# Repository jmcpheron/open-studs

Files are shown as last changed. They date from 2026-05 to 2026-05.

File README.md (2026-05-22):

# open-studs

**Design your own 3D-printable studded TPU bracelet in the browser.** Pick the
bracelet size, stud style, pattern, latch, and print stage, then export JSON or
OpenSCAD for STL generation.

[**Start Designing**](https://jmcpheron.github.io/open-studs/configurator/) ·
[Design Architecture](https://jmcpheron.github.io/open-studs/design-architecture.html) ·
[Latch Lab](https://jmcpheron.github.io/open-studs/latch-lab.html) ·
[Contributing](CONTRIBUTING.md)

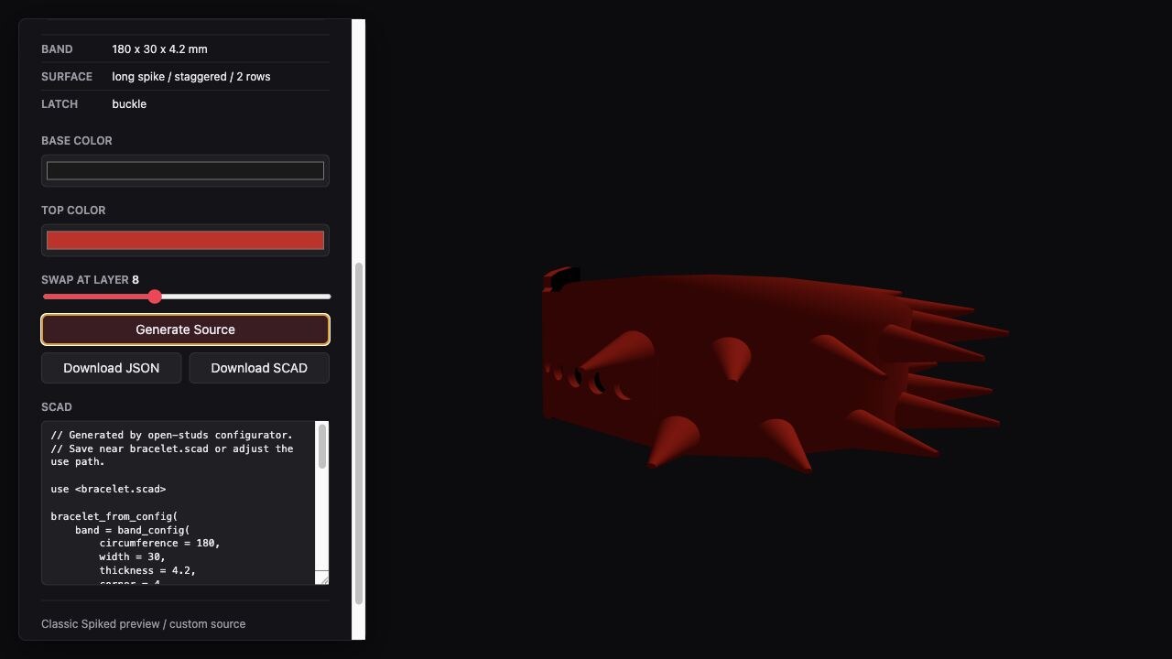
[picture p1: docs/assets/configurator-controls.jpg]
open-studs bracelet configurator


The configurator starts from printable presets, then lets you adjust the core
bracelet geometry: length, width, thickness, stud type, stud layout, attachment
mode, latch, and test-print stage. The preview shows the bracelet worn curved
around a wrist or laid flat in print orientation.

| Design in the Browser | Print-Orientation Preview |
| --- | --- |
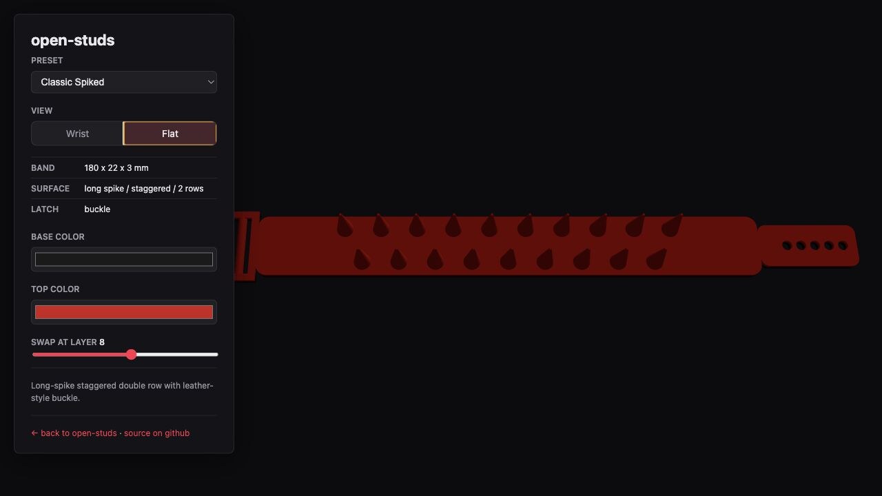
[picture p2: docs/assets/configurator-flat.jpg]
Flat print preview
| Configurator controls |  |

## Start Here

1. Open the [bracelet configurator](https://jmcpheron.github.io/open-studs/configurator/).
2. Choose a preset, then adjust band size, stud style, pattern, latch, and export stage.
3. Download JSON or SCAD. Build locally with `uv run studslab build-config configs/example_bracelet.json -o build/custom.stl`, or use the manual `build-config` GitHub Action.







**Parametric, 3D-printable studded bracelets in TPU.** Punk-and-metal aesthetic,
flexible like leather, open-source like it should be.

Designed in OpenSCAD. Browse presets at [jmcpheron.github.io/open-studs](https://jmcpheron.github.io/open-studs). Clone the repo to add your own stud designs, latches, or take it somewhere new.

This repo follows the **[Shareable CAD](SHAREABLE-CAD.md)** pattern: OpenSCAD as the parametric source-of-truth, Python kernel (`studslab`, `explainers`) for deconstruction, GitHub as the workshop, MakerWorld + Printables as the storefronts.

---

## What this is

A kit, not a single model. The band, the studs, the latches, and the placement patterns are all separate modules — mix and match to build the bracelet you want. Three ways to use it:

- **Just want to print one?** Grab a preset from [Printables](#) or [MakerWorld](#).
- **Want to customize?** Use the [web configurator](https://jmcpheron.github.io/open-studs/configurator/) — export JSON for `uv run studslab build-config` or SCAD for direct OpenSCAD builds.
- **Want to design your own?** Clone the repo, edit the OpenSCAD source, PR a new stud or latch back. Contributor docs in [CONTRIBUTING.md](CONTRIBUTING.md).

## Stud modes

Three ways to build a stud:

1. **Integral studs** — studs printed as part of the band in one piece. Cleanest look, single print, single color (unless you do a color-change pause or have multi-material).
2. **Modular studs** — band and studs printed separately, friction-fit or glued. Unlocks the iconic silver-on-black look without needing a multi-material printer.
3. **Bare band with attachment holes** — band only, with a grid of through-holes. Bring your own studs: foam spikes, metal hardware, rhinestones, fabric pieces, sewn-on whatever. The bracelet becomes a substrate.

## Built-in stud designs

- Classic pyramid
- Flat (low-profile) pyramid
- Dome / half-sphere
- Cone spike
- Long spike (the dramatic one)
- Diamond
- Screw-head (flat round)
- *...and whatever the community adds*

## Latch options

Different tradeoffs — none is universally best:

- **Buckle (pin-through-hole)** — most leather-bracelet-authentic, adjustable for wrist size, very secure
- **Snap button (printed peg + socket)** — lowest profile, fastest to put on
- **Loop-and-post / toggle** — secure, hides well under studs
- **Friction overlap** — no hardware, fully adjustable, TPU-on-TPU grip (may slip in heavy use)
- **Magnetic insert pocket** — premium feel, requires a small neodymium magnet
- *...and whatever the community adds*

Experimental latch coupons live in [docs/latch-lab.md](docs/latch-lab.md):
`mushroom_keyhole`, `ladder_strap`, and `loop_post_v2`.

## Sizing

**Print a test strip before committing to a full bracelet.** TPU stretch varies by brand and infill, and wrist sizes vary more than you'd think. The repo includes `sizing_test.scad` plus focused coupons under `test_prints/` for flex relief, surface attachment, and latch fit.

Rough guide:
- Kid: 140–160mm circumference
- Small adult: 160–180mm
- Medium adult: 175–195mm
- Large adult: 190–215mm

## Printing notes

- **Filament:** TPU 95A is the sweet spot — flexible enough to slip on, stiff enough to hold studs. TPU 85A works but is floppy. TPU 98A+ is too stiff for the friction latch mode.
- **Layer height:** 0.2mm is fine. 0.15mm for cleaner stud detail.
- **Infill:** 100% — TPU prints best as solid perimeters; partial infill on flexible parts looks bad and weakens the band.
- **Supports:** generally no. The studs are designed to print without support; check the preview if you're modifying placement.
- **Speed:** slow down for TPU. 20–30mm/s is typical.
- **Tip radius:** the spike-style studs have a `tip_radius` parameter. Default is rounded for safety. Set to zero for the full sharp aesthetic — your call, your wrist.

## Repository layout

```
open-studs/
├── bracelet.scad           # public assembly entry point
├── core/                   # band, surface, latch, and config assembly layers
├── sizing_test.scad        # calibration strip — print this first
├── studs/                  # one file per stud design
│   ├── pyramid.scad
│   ├── dome.scad
│   ├── cone_spike.scad
│   ├── long_spike.scad
│   ├── diamond.scad
│   ├── flat_pyramid.scad
│   └── screw_head.scad
├── latches/                # one file per latch
│   ├── buckle.scad
│   ├── snap.scad
│   ├── loop_post.scad
│   ├── friction_overlap.scad
│   └── magnetic.scad
├── patterns/               # stud placement strategies
│   ├── single_row.scad
│   ├── double_row.scad
│   ├── staggered.scad
│   ├── cluster.scad
│   └── gradient_size.scad
├── presets/                # ready-to-print hero configurations
│   ├── classic_spiked.scad
│   ├── festival_wide.scad
│   └── subtle_daily.scad
├── test_prints/            # focused fit and attachment coupons
├── docs/                   # configurator (GitHub Pages)
└── gallery/                # printed examples
```

## Quick start (OpenSCAD)

```scad
use <bracelet.scad>

studded_bracelet(
    circumference = 180,
    width         = 22,
    thickness     = 3,
    stud_module   = "long_spike",
    stud_pattern  = "staggered",
    stud_rows     = 2,
    latch         = "buckle",
    mode          = "integral"   // or "modular" or "bare_with_holes"
);
```

## Contributing

The whole point is that you can add your own studs and latches and PR them back. See [CONTRIBUTING.md](CONTRIBUTING.md) — there's a template stud file, a shared module signature every stud must implement, and a checklist for getting your design merged.
The current band/surface/latch/export split is documented in [docs/design-architecture.md](docs/design-architecture.md).

Particularly looking for:
- New stud designs (especially anything that captures a specific subculture — goth, festival, cyberpunk, kawaii, etc.)
- New latch mechanisms with different tradeoffs
- Multi-material / AMS-aware variants
- Form-factor extensions (collars, chokers, belts, guitar straps — the stud library is reusable)

## License

Dual-licensed:

- **Source code** (`.scad` files, configurator JS, build scripts) — [MIT](LICENSE-MIT)
- **Design output and docs** (STL files, 3MF presets, printed objects, photos, gallery, README) — [CC BY 4.0](LICENSE-CC-BY)

Both licenses are permissive. You can use this commercially, modify it, sell prints of it, ship it inside a closed-source product — anything. The only requirement is attribution: credit `open-studs` and link back. For source code, that means keeping the copyright notice and MIT text in the files. For physical prints or marketplace listings, that means a visible credit somewhere reasonable (product description, included card, etc.).

Modifications you make can be released under whatever license you want, including closed/proprietary — but the original `open-studs` work stays under these licenses for everyone, forever.

## Credits

Built by Jason McPheron. Punk aesthetic direction by Audrey. Contributions from [the community](https://github.com/jmcpheron/open-studs/graphs/contributors).

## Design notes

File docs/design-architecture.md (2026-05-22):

# Bracelet Design Architecture

`open-studs` now separates the bracelet into four layers that match both the
OpenSCAD assembly and the GitHub Pages configurator data.

## Band

Physical substrate:

- `circumference`
- `width`
- `thickness`
- `corner`
- `flex_relief`
- `relief_pitch`
- `relief_width`
- `relief_depth`

The band prints flat. `flex_relief = "inside_slots"` cuts small underside
slots into thicker bands so TPU can curve around the wrist without forcing the
top surface design to carry the bend.

## Surface

Top-side design and attachment strategy:

- `mode`: `integral`, `modular`, or `bare_with_holes`
- `stud_module`
- `stud_pattern`
- `stud_rows`
- `stud_size`
- `tip_radius`
- `stud_spacing`

Integral mode unions studs onto the band. Modular mode subtracts shallow
sockets. Bare-with-holes mode subtracts through-holes for third-party hardware.

## Latch

Closure choice and keepout:

- `type`: `buckle`, `snap`, `loop_post`, `friction_overlap`, `magnetic`, or `none`
- `clearance`

Latch geometry is assembled separately from the surface design. The clearance
keeps studs and flex slots out of latch hardware space.

## Export Stage

The same config can emit different printable artifacts:

- `print_flat`: complete bracelet STL in print orientation
- `band_only`: substrate-only coupon or blank
- `surface_only`: band plus top design, no latch
- `latch_only`: short latch fit coupon

The web viewer keeps the baked STL flat for printing and applies the wrist bend
as a display transform only. That keeps the generated STL faithful to the print
orientation while still showing how the design wears.

## Configurator JSON

The GitHub Pages configurator exports the same four-part structure as JSON:

```json
{
  "schemaVersion": 1,
  "band": {
    "circumference": 180,
    "width": 22,
    "thickness": 3,
    "corner": 4,
    "flexRelief": "none",
    "reliefPitch": 10,
    "reliefWidth": 1.2
  },
  "surface": {
    "mode": "integral",
    "stud": "pyramid",
    "pattern": "single_row",
    "rows": 1,
    "studSize": 6,
    "tipRadius": 0.4,
    "studSpacing": null
  },
  "latch": {
    "type": "mushroom_keyhole",
    "clearance": 25
  },
  "export": {
    "stage": "print_flat",
    "testLength": 70
  }
}
```

Build a downloaded config locally:

```sh
uv run studslab build-config configs/example_bracelet.json -o build/example_bracelet.stl
```

Or run the manual `build-config` GitHub Action against a committed JSON config
path, such as `configs/example_bracelet.json`. The action writes the generated
SCAD wrapper to `docs/configurator/generated/` and the STL to
`docs/configurator/stls/`.

## SCAD Entry Points

Hand-authored files can keep using the flat compatibility API:

```scad
use <bracelet.scad>

studded_bracelet(
    circumference = 180,
    width         = 22,
    thickness     = 3,
    stud_module   = "long_spike",
    stud_pattern  = "staggered",
    stud_rows     = 2,
    latch         = "buckle",
    mode          = "integral"
);
```

Generated/configurator-driven files can use grouped configs:

```scad
use <bracelet.scad>

bracelet_from_config(
    band = band_config(
        circumference = 190,
        width = 28,
        thickness = 5,
        flex_relief = "inside_slots"
    ),
    surface = surface_config(
        mode = "integral",
        stud_module = "star",
        stud_pattern = "double_row",
        stud_rows = 2,
        stud_size = 8
    ),
    latch = latch_config(type = "loop_post"),
    export = export_config(stage = "print_flat")
);
```

## Test Prints

Build focused coupons before a full bracelet:

```sh
uv run studslab build test_prints/flex_relief_strip.scad -o build/test_prints/flex_relief_strip.stl
uv run studslab build test_prints/surface_attachment_strip.scad -o build/test_prints/surface_attachment_strip.stl
uv run studslab build test_prints/latch_sampler.scad -o build/test_prints/latch_sampler.stl
```

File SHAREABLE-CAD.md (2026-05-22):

# Shareable CAD — the pattern this repo is built on

> *A pipeline for hand-printable, parametric, code-trackable, community-shareable 3D objects. A parametric source-of-truth on top; a Python kernel that deconstructs it in the middle; GitHub as the workshop; MakerWorld and Printables as the storefronts.*

This repo is the fourth project to follow the pattern, after the **PyCon 2026 gear card**, the **Pounce-a-Pult** spiral-spring cat toy, and the **Adam Savage mini vault door** study. Where those three use **Onshape** as the parametric source (with STEP exports committed into git), `open-studs` uses **OpenSCAD** — the `.scad` files in this repo *are* the source of truth, no STEP-export bridge required. Everything else from the pattern carries over.

## TL;DR

```
   OpenSCAD source       ← parametric source of truth (.scad in git)
       │
       ▼
   GitHub repo           ← Python toolkit, parameter mirror, history, issues
       │ auto-built artifacts (STL / PNG / GIF / explainer pages)
       ▼
   MakerWorld + Printables   ← consumer-facing sharing endpoints
                              (3MF bundle + slicer profile + photos)
```

`.scad` files are already code-trackable, so the Onshape-as-source variants of this pattern need an export step that `open-studs` skips. The parametric source lives in `bracelet.scad`, `core/*.scad`, `studs/*.scad`, `latches/*.scad`, and `patterns/*.scad`. A Python parameter mirror at [`src/open_studs/params.py`](src/open_studs/params.py) holds the same numbers as Python constants, kept in sync by discipline and enforced by a drift test. A Python toolkit at [`src/studslab/`](src/studslab/) does the deconstruction — inspect, render, build, explode, spin. An explainer generator at [`src/explainers/`](src/explainers/) produces docs pages from the parameter file.

## What makes something "shareable CAD"

The word does a lot of work. People share STLs on Thingiverse every day; that's not what this pattern is about. What we mean:

1. **Parametric.** The object isn't a frozen mesh — it's a small number of parameters that *produce* a mesh. Change a tooth count, a diameter, a thickness, a stud spacing, and the whole thing re-derives.
2. **Single source of truth.** Every dimension lives in exactly one place. For `open-studs`, that place is the `.scad` files; a Python mirror restates the same numbers for documentation; a drift test yells if the numbers diverge.
3. **Code-trackable.** A parameter change is a one-line git diff with a commit message and a date.
4. **Derivable.** Every artifact a reader might want — exploded GIF, per-part STL, hero PNG, explainer page — is *built* by code that reads only from the source of truth. No artisanal copies.
5. **Printable.** The end-state of the whole loop is a 3D print someone else can produce in their own kitchen with a printer they already own, without having to know any of the above.

## The projects so far

| Project | Source-of-truth tool | Status | Lives on | Doc |
|---|---|---|---|---|
| Gear card (PyCon 2026) | Onshape | shipped | GitHub | pycon2026 repo |
| Pounce-a-Pult | Onshape | shipped | MakerWorld + GitHub | pycon2026 repo |
| Adam Savage mini vault | Onshape | in progress | GitHub | pycon2026 repo |
| **open-studs** | **OpenSCAD** | **vertical slice** | **GitHub** | [`README.md`](README.md) |

`open-studs` is the first project in the pattern to use OpenSCAD as the source-of-truth. The earlier three use Onshape because their geometry (gears, splines, threaded inserts) is much easier to design with mate-and-relation cloud CAD. A parametric **library of swappable modules** like `open-studs` is naturally code-first — every stud is a `module`, every pattern is a `function`, every latch is a `module`, and the band assembles them with string dispatch.

## OpenSCAD as source-of-truth — what changes vs. the Onshape variants

| Stage | Onshape variant (gear card, vault) | OpenSCAD variant (open-studs) |
|---|---|---|
| Editing surface | Onshape Part Studio variables sheet | `.scad` files |
| Source-of-truth file | Onshape doc → STEP exported to repo root | `.scad` directly in git |
| Sync to Python mirror | Hand-edit `params.py` to match Onshape variables | Hand-edit `params.py` to match `.scad` defaults |
| Drift enforcement | Drift test on parameter file vs. docs | Drift test on parameter file vs. docs |
| Public design URL | Onshape doc share link | Direct link to the `.scad` files |
| CI render dependency | `cadquery-ocp` / `build123d` (~180 MB OpenCascade) | `openscad` CLI (system package, much smaller) |

The OpenSCAD variant is **lighter** on the build side — no OpenCascade wheel, much faster CI — and **less ergonomic** for visualizing assembled motion (an Onshape Assembly tab beats `.scad` for "watch the gears mesh"). For a static library of swappable parts, the trade is worth it.

## The Python parameter mirror

[`src/open_studs/params.py`](src/open_studs/params.py) holds every dimension that has a default in the SCAD files: band defaults (`BAND_DEFAULT_CIRCUMFERENCE`, `BAND_DEFAULT_WIDTH`, `BAND_DEFAULT_THICKNESS`), stud defaults (`STUD_DEFAULT_SIZE`, `STUD_DEFAULT_TIP_RADIUS`), latch defaults (`BUCKLE_HOLES`, `BUCKLE_HOLE_SPACING`, `BUCKLE_HOLE_DIAMETER`), pattern defaults (`SINGLE_ROW_DEFAULT_SPACING`).

Other Python code (explainers, charts, tests) reads only from `params.py`. The drift test (Push 2) asserts that every number listed in `params.py` also appears in any markdown that references that number — so a one-side change fails CI.

Keeping `params.py` in sync with `.scad` defaults is by hand for now. The friction point most worth automating eventually is generating `params.py` *from* a small JSON header in each `.scad` file, but that's down the road.

## The Python kernel

The two packages are the *lab* — small CLIs that demonstrate "processing parametric 3D files at consumer-community level."

[`studslab`](src/studslab/) is the workhorse:

| Command | Does |
|---|---|
| `studslab inspect <scad>` | Parse the top-level parameters of a `.scad` file and print a table. Pure-Python, no OpenSCAD CLI dep. |
| `studslab render <scad>` | Shell out to `openscad` to produce a PNG (iso / top / side angles). |
| `studslab build <scad>` | Shell out to `openscad -o out.stl in.scad`. |
| `studslab build-config <json>` | Convert a configurator JSON export to a temporary SCAD wrapper and build an STL. |
| `studslab explode <scad>` | For modular mode: render the band, each stud variant, and the latch as separate STLs. |
| `studslab spin <scad>` | Renders a rotating GIF — bracelet on a turntable, frames stitched by Pillow. |

[`explainers`](src/explainers/) generates per-page writeups from `params.py` — markdown plus SVG diagrams via `drawsvg`. Push 1 ships a skeleton; Push 2 wires up the first explainer (the stud size guide).

The packages split into a **light toolchain** (drawsvg + matplotlib, fast install, builds the explainer pages) and a **heavy toolchain** (Pillow + the `openscad` CLI on PATH, builds the STEP-derived renders). See [`pyproject.toml`](pyproject.toml).

## GitHub as the workshop

The repo's working pattern, generalised:

1. **The README tells the story.** Hero render at the top (or will, once Push 3's CI starts auto-building one). Not "documentation" — narrative.
2. **CI auto-builds derived artifacts on push.** Three workflows planned: `build-scad.yml` watches `*.scad` and rebuilds PNGs; `build-explainers.yml` watches `src/explainers/` and `params.py` and rebuilds pages; `pages.yml` publishes `docs/` to github.io. (These ship in Push 3.)
3. **Issues are for design discussion.** "Should the buckle have 5 holes or 7?" is an issue, not a Slack thread.
4. **PRs are for parameter changes and new modules.** A new stud is a PR; a tweak to the pyramid's tip radius is a PR; the diff includes the regenerated docs.
5. **GitHub Pages deploys `docs/`** so non-cloners can still read.

## MakerWorld + Printables as the storefronts

Once enough presets exist, ship them to both:

- **MakerWorld** — owned by Bambu Lab, the dominant consumer 3D-printer maker. Bundles slicer profiles with prints, dramatically lowers "first print works" failure rate. Audience is enormous.
- **Printables** — owned by Prusa. Looser, more open. Default share-license is more permissive. Smaller audience, sturdier community.

The pattern is to publish to **both**, with the bundle as the binary artifact and the GitHub repo as the parametric source. Each listing links back to the others:

```
   MakerWorld listing ──► ──► ──► GitHub repo ──► .scad source
              ▲                       │
              └─── Printables listing ┘
```

For `open-studs`, the first preset to ship will be **Classic Spiked** — long-spike pattern, single row, buckle latch, medium adult size, 22 mm wide.

## The open-source ↔ consumer-friendly tension

If MakerWorld is closed-ish, why publish there? Because a first-time 3D-printer owner with a Bambu A1 in their kitchen is more likely to open the Bambu Handy app and search MakerWorld than to clone a git repo. Pretending otherwise just keeps a smaller audience.

The core belief:

- **The source of truth stays open.** The `.scad` files are MIT-licensed. Anyone can fork and remix.
- **The derived bundle goes where the audience is.** MakerWorld gets a 3MF + slicer profile + photos. The bundle is the "click to print" consumer thing — it isn't where remixing happens, it's where the audience already lives.
- **Every listing links back.** A MakerWorld viewer sees, in the description, "Full source on GitHub" and "Web configurator at jmcpheron.github.io/open-studs." A GitHub visitor sees the MakerWorld link in the README. Nobody is trapped in any single platform.

The dual licensing (MIT for code, CC BY 4.0 for design output — see [`LICENSE`](LICENSE)) is the legal expression of this stance. The dual-publish pattern is the practical one.

## What's different about open-studs

Two things, both because `open-studs` is a **kit**, not a single object:

1. **The web configurator is a real planned endpoint, not just a remix surface.** Punk bracelets are personal — wrist size, stud type, pattern, latch all vary by wearer. A web configurator (planned: `openscad-wasm` running in-browser at `jmcpheron.github.io/open-studs`) lets people customize *before* downloading, instead of cloning and editing. This is additive to MakerWorld/Printables, not a replacement: presets go to the storefronts; one-offs come through the configurator.
2. **Contributor PRs are first-class.** The earlier projects in this pattern are single objects with a single author. `open-studs` is a kit where the community is supposed to add studs, latches, and patterns. [`CONTRIBUTING.md`](CONTRIBUTING.md) is therefore a load-bearing doc; the module signature contract there is the most important interface in the repo.

## Companion docs

- [`README.md`](README.md) — the front-door story.
- [`CONTRIBUTING.md`](CONTRIBUTING.md) — how to add a stud / latch / pattern.
- [`ACKNOWLEDGMENTS.md`](ACKNOWLEDGMENTS.md) — third-party tools and licenses.
- [`docs/devlog/`](docs/devlog/) — build journal, informal, dated.
- [`docs/explainers/`](docs/explainers/) — auto-generated parameter-driven pages (skeleton in Push 1; first real page in Push 2).

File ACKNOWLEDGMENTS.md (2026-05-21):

# Acknowledgments

## People

- **Jason McPheron** — project lead, OpenSCAD source, Python toolkit.
- **Audrey** — punk aesthetic direction, stud design taste, wrist model.
- **The community** — every stud, latch, and pattern PR'd into the repo. See the [contributors page](https://github.com/jmcpheron/open-studs/graphs/contributors).

## Pattern

`open-studs` is the fourth project to follow the **Shareable CAD** pattern, after the PyCon 2026 gear card, the Pounce-a-Pult cat toy, and the Adam Savage mini vault door. See [`SHAREABLE-CAD.md`](SHAREABLE-CAD.md).

## Third-party tools

| Tool | What it does for us | License |
|---|---|---|
| [OpenSCAD](https://openscad.org/) | Parametric CAD source-of-truth. `.scad` files in this repo are read by OpenSCAD, locally and in CI. | GPL-2.0-or-later |
| [drawsvg](https://github.com/cduck/drawsvg) | SVG generation for explainer-page diagrams. | MIT |
| [matplotlib](https://matplotlib.org/) | Charts in explainer pages. | matplotlib (BSD-style) |
| [Pillow](https://python-pillow.org/) | Stitches OpenSCAD frame renders into animated GIFs. | HPND |
| [uv](https://github.com/astral-sh/uv) | Python toolchain & dependency manager. | MIT / Apache-2.0 |
| [pytest](https://pytest.org/) | Test runner — drift tests and signature tests. | MIT |

OpenSCAD is GPL; we use it as a build tool (calling its CLI), which doesn't impose copyleft on this repo's source. The `.scad` files themselves are MIT, the printed outputs are CC BY 4.0.

## Communities

- **Printables** and **MakerWorld** — the consumer-facing 3D-printing communities where presets eventually ship. Both are referenced from this repo's listings when they go live.
- The wider **OpenSCAD community** — for keeping the language alive, for `BOSL2`/`MCAD`/etc. which we may pull from in future contributions.

## Inspiration

The bracelet itself is a software-defined love letter to leather-and-studs punk fashion — a tradition that long predates either of us and that we have no ownership of. We're just translating it into TPU. If you wear one to a show, that's the highest compliment.

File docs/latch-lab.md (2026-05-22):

# Latch Lab

This is the fast feedback loop for bracelet closures. Each latch starts as a
small coupon before it earns its way onto a full bracelet.

## Print Protocol

Print the coupon in TPU before changing a full bracelet:

```sh
uv run studslab build test_prints/latch_lab_three_pack.scad -o build/test_prints/latch_lab_three_pack.stl
```

Use the same TPU, layer height, and wall settings you expect for the bracelet.
Try each latch one-handed, then tug it open and closed at least 20 times.

## Scorecard

Use 1-5 for each:

| Latch | Holds pull | Closes one-handed | Opens intentionally | Comfortable underside | Notes |
| --- | ---: | ---: | ---: | ---: | --- |
| mushroom_keyhole | | | | | |
| ladder_strap | | | | | |
| loop_post_v2 | | | | | |

Useful notes are blunt and physical: "entry hole too tight", "post too tall",
"slot tears white", "digs into wrist", "easy but ugly", "secure but slow".

## Candidates

### `mushroom_keyhole`

Low-profile mushroom post on one end, keyhole tab on the other. The large hole
lets the head through; the narrow throat captures the shaft under tension.

What to watch:

- whether the mushroom head is too hard to push through
- whether the throat holds under wrist flex
- whether the post is too tall on the inside of the wrist

### `ladder_strap`

Adjustable ladder slots stretch over a low catch. This is the practical sizing
candidate: less elegant, more forgiving.

What to watch:

- which slot feels like the real engagement point
- whether the slots tear or whiten
- whether the catch block is too sharp or too low

### `loop_post_v2`

Lower, inboard loop-post with a guided keyhole instead of a plain loop. This is
the aesthetic candidate if it can be made comfortable.

What to watch:

- whether the loop tab bends enough to engage
- whether the relief dots help or create tear starts
- whether the lower post still captures reliably

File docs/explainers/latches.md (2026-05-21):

# Latch catalog

> Auto-generated from `src/open_studs/params.py`.

## Buckle

Pin-through-hole, leather-bracelet authentic.

- Adjustment holes: **5**, spaced **5 mm** apart
- Hole diameter: 3.5 mm
- Printed pin diameter: 3.2 mm
- Total adjustability: 20 mm

## Snap

Printed peg-and-socket. Both ends have a flat tab extending past the band edge. The left tab carries a small flared peg; the right tab carries a matching socket in its underside. Wrap the band, lay the right tab over the left, press to snap. No hardware.

## Loop-post

T-headed post on the left end (rises from the band's top surface). Loop frame on the right end (extends past the band). Wrap, slip the loop over the post, the T-head captures it. Slim profile.

## Friction-overlap

No added hardware. The band's own ends taper slightly; TPU-on-TPU grip holds the overlap. Fully adjustable but may slip under heavy use.

## Magnetic

Small puck at each band end with a recessed pocket sized for a **6 mm × 2 mm** neodymium disc magnet. User glues a magnet into each pocket after printing (cyanoacrylate). Polarity is the user's responsibility — mark the magnets before gluing because you cannot reverse it once cured.

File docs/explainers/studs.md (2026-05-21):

# Stud catalog

> Auto-generated from `src/open_studs/params.py`.

Default size: 6 mm base.
Default tip radius: 0.4 mm (safety-rounded;
set to 0 for the sharp variant).

Height multipliers, relative to the base size:

| Stud | Height multiplier |
|---|---|
| pyramid | × 1.00 |
| dome | × 0.50 |
| cone_spike | × 1.20 |
| long_spike | × 2.50 |
| diamond | × 1.40 |
| flat_pyramid | × 0.40 |
| screw_head | × 0.25 |
| rivet | × 0.40 |
| hex_bolt | × 0.50 |
| washer | × 0.25 |
| star | × 0.35 |
| heart | × 0.35 |
| lightning | × 0.35 |

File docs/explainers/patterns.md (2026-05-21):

# Stud-placement patterns

> Auto-generated from `src/open_studs/params.py`.

## Working

- **`single_row`** — evenly-spaced studs along the centerline. Default spacing 12 mm.
- **`double_row`** — two parallel rows. Default spacing 12 mm.
- **`staggered`** — two rows offset by half a step. Default spacing 12 mm. Classic punk look.

## Stubs

- **`cluster`** — small groups with gaps between. Signature locked, topology TBD.
- **`gradient_size`** — varying stud sizes along the band. Needs signature extension.

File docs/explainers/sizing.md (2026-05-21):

# Sizing guide

> Auto-generated from `src/open_studs/params.py`. Do not edit by hand —
> change the numbers in `params.py` and rebuild.

Wrist circumference ranges:

| Wearer | Range |
|---|---|
| Kid | 140–160 mm |
| Small Adult | 160–180 mm |
| Medium Adult | 175–195 mm |
| Large Adult | 190–215 mm |

Defaults shipped in `bracelet.scad`:

- `circumference = 180 mm` (medium adult)
- `width         = 22 mm`
- `thickness     = 3 mm`

Always print [`sizing_test.scad`](../../sizing_test.scad) before committing
to a full bracelet. TPU stretch varies by brand.

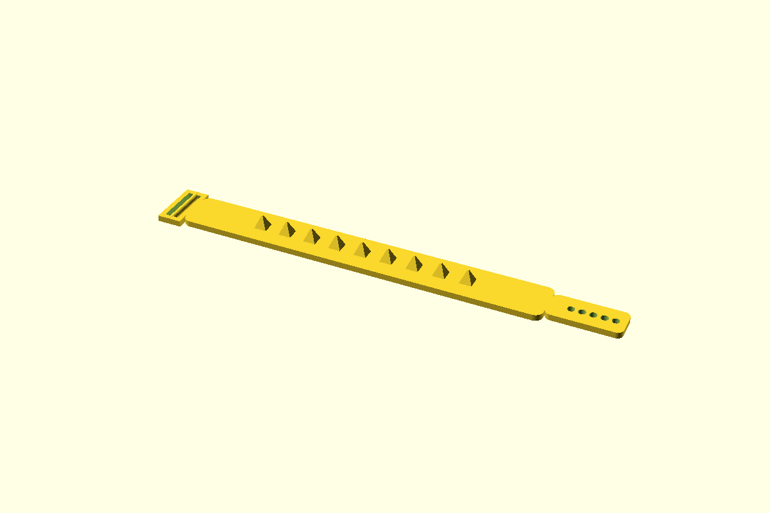
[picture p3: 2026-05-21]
docs/assets/bracelet.png

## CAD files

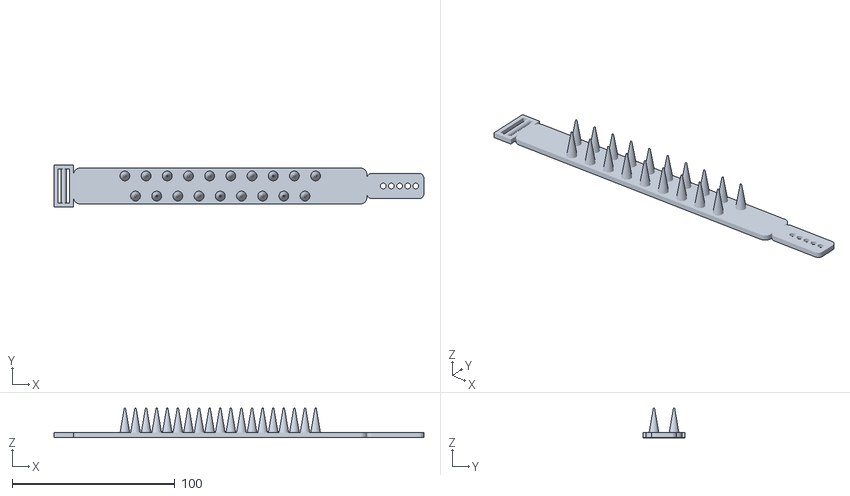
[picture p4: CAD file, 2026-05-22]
docs/configurator/stls/classic_spiked.stl
227.0 x 26.0 x 18.1

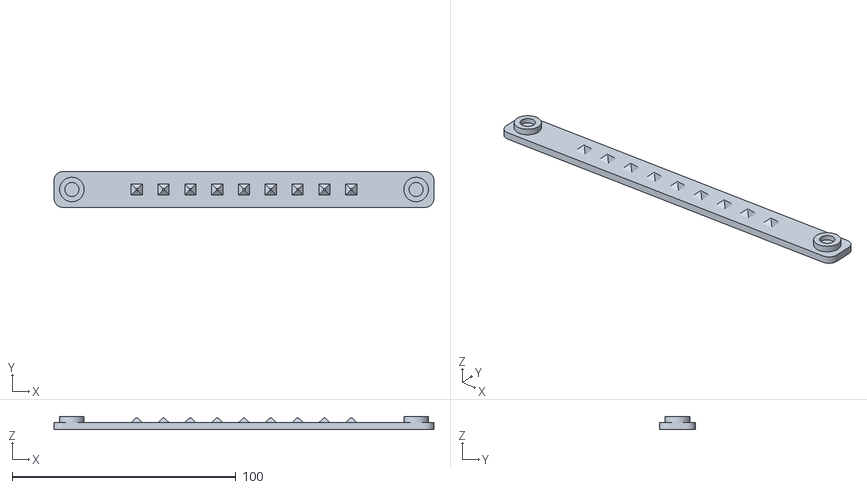
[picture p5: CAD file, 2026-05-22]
docs/configurator/stls/subtle_daily.stl
170.0 x 16.0 x 5.60

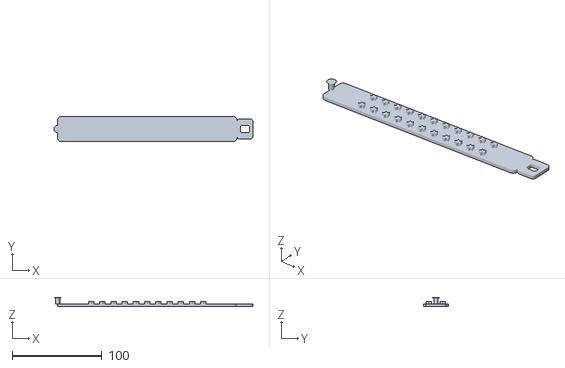
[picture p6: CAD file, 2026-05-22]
docs/configurator/stls/festival_wide.stl
222.0 x 28.0 x 10.0

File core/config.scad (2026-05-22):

// core/config.scad — grouped design configuration helpers.
// MIT licensed. See LICENSE-MIT.
//
// The public `studded_bracelet(...)` API stays flat for hand editing, but the
// assembly uses these grouped configs internally. They mirror the GitHub Pages
// configurator sections: band, surface, latch, and export stage.

OPEN_STUDS_FN = 48;

OPEN_STUDS_DEFAULT_CIRCUMFERENCE = 180;
OPEN_STUDS_DEFAULT_WIDTH         = 22;
OPEN_STUDS_DEFAULT_THICKNESS     = 3;
OPEN_STUDS_DEFAULT_CORNER        = 4;
OPEN_STUDS_LATCH_MARGIN          = 25;

OPEN_STUDS_DEFAULT_STUD          = "pyramid";
OPEN_STUDS_DEFAULT_PATTERN       = "single_row";
OPEN_STUDS_DEFAULT_ROWS          = 1;
OPEN_STUDS_DEFAULT_STUD_SIZE     = 6;
OPEN_STUDS_DEFAULT_TIP_RADIUS    = 0.4;

OPEN_STUDS_DEFAULT_SOCKET_DEPTH  = 1.5;
OPEN_STUDS_DEFAULT_HOLE_DIAMETER = 3;

// --- band config -----------------------------------------------------------

function band_config(
    circumference      = OPEN_STUDS_DEFAULT_CIRCUMFERENCE,
    width              = OPEN_STUDS_DEFAULT_WIDTH,
    thickness          = OPEN_STUDS_DEFAULT_THICKNESS,
    corner             = OPEN_STUDS_DEFAULT_CORNER,
    flex_relief        = "none",
    relief_pitch       = 10,
    relief_width       = 1.2,
    relief_depth       = undef,
    relief_edge_margin = 2,
    relief_margin      = OPEN_STUDS_LATCH_MARGIN
) = [
    circumference,
    width,
    thickness,
    corner,
    flex_relief,
    relief_pitch,
    relief_width,
    relief_depth,
    relief_edge_margin,
    relief_margin
];

function band_cfg_length(c)             = c[0];
function band_cfg_width(c)              = c[1];
function band_cfg_thickness(c)          = c[2];
function band_cfg_corner(c)             = c[3];
function band_cfg_flex_relief(c)        = c[4];
function band_cfg_relief_pitch(c)       = c[5];
function band_cfg_relief_width(c)       = c[6];
function band_cfg_relief_depth(c)       = c[7];
function band_cfg_relief_edge_margin(c) = c[8];
function band_cfg_relief_margin(c)      = c[9];

// --- surface config --------------------------------------------------------

function surface_config(
    mode            = "integral",
    stud_module     = OPEN_STUDS_DEFAULT_STUD,
    stud_pattern    = OPEN_STUDS_DEFAULT_PATTERN,
    stud_rows       = OPEN_STUDS_DEFAULT_ROWS,
    stud_size       = OPEN_STUDS_DEFAULT_STUD_SIZE,
    tip_radius      = OPEN_STUDS_DEFAULT_TIP_RADIUS,
    stud_spacing    = undef,
    socket_depth    = OPEN_STUDS_DEFAULT_SOCKET_DEPTH,
    socket_diameter = undef,
    hole_diameter   = OPEN_STUDS_DEFAULT_HOLE_DIAMETER
) = [
    mode,
    stud_module,
    stud_pattern,
    stud_rows,
    stud_size,
    tip_radius,
    stud_spacing,
    socket_depth,
    socket_diameter,
    hole_diameter
];

function surface_cfg_mode(c)            = c[0];
function surface_cfg_stud_module(c)     = c[1];
function surface_cfg_pattern(c)         = c[2];
function surface_cfg_rows(c)            = c[3];
function surface_cfg_stud_size(c)       = c[4];
function surface_cfg_tip_radius(c)      = c[5];
function surface_cfg_spacing(c)         = c[6];
function surface_cfg_socket_depth(c)    = c[7];
function surface_cfg_socket_diameter(c) = c[8];
function surface_cfg_hole_diameter(c)   = c[9];

// --- latch config ----------------------------------------------------------

function latch_config(
    type      = "buckle",
    clearance = OPEN_STUDS_LATCH_MARGIN
) = [
    type,
    clearance
];

function latch_cfg_type(c)      = c[0];
function latch_cfg_clearance(c) = c[1];

// --- export config ---------------------------------------------------------

function export_config(
    stage       = "print_flat",
    test_length = 70
) = [
    stage,
    test_length
];

function export_cfg_stage(c)       = c[0];
function export_cfg_test_length(c) = c[1];

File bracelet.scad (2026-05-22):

// open-studs — parametric studded bracelet, source-of-truth.
// MIT licensed. See LICENSE-MIT.
//
// Top-level entry points:
//   - studded_bracelet(...): flat, hand-editable compatibility API.
//   - bracelet_from_config(...): segmented band/surface/latch/export API.
//
// The bracelet is exported flat for printing. The GitHub Pages viewer can
// bend that same STL around a wrist for preview without changing the print
// orientation.
//
// Quick start:
//
//   use <bracelet.scad>
//   studded_bracelet(
//       circumference = 180, width = 22, thickness = 3,
//       stud_module = "long_spike", stud_pattern = "staggered",
//       stud_rows = 2, latch = "buckle", mode = "integral"
//   );

include <core/config.scad>

use <core/band.scad>
use <core/surface.scad>
use <core/latch.scad>

$fn = OPEN_STUDS_FN;

// Compatibility constant for older user files and pattern discussions.
LATCH_MARGIN = OPEN_STUDS_LATCH_MARGIN;

// --- assembly stages -------------------------------------------------------

module bracelet_from_config(
    band    = band_config(),
    surface = surface_config(),
    latch   = latch_config(),
    export  = export_config()
) {
    stage = export_cfg_stage(export);

    if (stage == "print_flat") {
        _bracelet_print_flat(band, surface, latch);
    } else if (stage == "band_only") {
        bracelet_band_from_config(band);
    } else if (stage == "surface_only") {
        _bracelet_surface_only(band, surface, latch);
    } else if (stage == "latch_only") {
        _bracelet_latch_test(band, latch, export);
    } else {
        echo(str(
            "WARN: unknown export stage '", stage,
            "'; valid: print_flat, band_only, surface_only, latch_only"
        ));
        _bracelet_print_flat(band, surface, latch);
    }
}

module _bracelet_print_flat(band, surface, latch) {
    difference() {
        union() {
            bracelet_band_from_config(band);
            bracelet_surface_from_config(surface, band, latch);
            bracelet_latch_from_config(latch, band);
        }

        bracelet_surface_cutouts_from_config(surface, band, latch);
    }
}

module _bracelet_surface_only(band, surface, latch) {
    difference() {
        union() {
            bracelet_band_from_config(band);
            bracelet_surface_from_config(surface, band, latch);
        }

        bracelet_surface_cutouts_from_config(surface, band, latch);
    }
}

module _bracelet_latch_test(band, latch, export) {
    test_band = band_config(
        circumference      = export_cfg_test_length(export),
        width              = band_cfg_width(band),
        thickness          = band_cfg_thickness(band),
        corner             = band_cfg_corner(band),
        flex_relief        = "none",
        relief_margin      = latch_cfg_clearance(latch)
    );

    union() {
        bracelet_band_from_config(test_band);
        bracelet_latch_from_config(latch, test_band);
    }
}

// --- public compatibility API ---------------------------------------------

module studded_bracelet(
    circumference      = OPEN_STUDS_DEFAULT_CIRCUMFERENCE,
    width              = OPEN_STUDS_DEFAULT_WIDTH,
    thickness          = OPEN_STUDS_DEFAULT_THICKNESS,
    stud_module        = OPEN_STUDS_DEFAULT_STUD,
    stud_pattern       = OPEN_STUDS_DEFAULT_PATTERN,
    stud_rows          = OPEN_STUDS_DEFAULT_ROWS,
    stud_size          = OPEN_STUDS_DEFAULT_STUD_SIZE,
    tip_radius         = OPEN_STUDS_DEFAULT_TIP_RADIUS,
    stud_spacing       = undef,
    latch              = "buckle",
    mode               = "integral",
    flex_relief        = "none",
    relief_pitch       = 10,
    relief_width       = 1.2,
    relief_depth       = undef,
    latch_clearance    = OPEN_STUDS_LATCH_MARGIN,
    stage              = "print_flat",
    test_length        = 70
) {
    band_cfg = band_config(
        circumference = circumference,
        width         = width,
        thickness     = thickness,
        flex_relief   = flex_relief,
        relief_pitch  = relief_pitch,
        relief_width  = relief_width,
        relief_depth  = relief_depth,
        relief_margin = latch_clearance
    );

    surface_cfg = surface_config(
        mode         = mode,
        stud_module  = stud_module,
        stud_pattern = stud_pattern,
        stud_rows    = stud_rows,
        stud_size    = stud_size,
        tip_radius   = tip_radius,
        stud_spacing = stud_spacing
    );

    latch_cfg = latch_config(
        type      = latch,
        clearance = latch_clearance
    );

    export_cfg = export_config(
        stage       = stage,
        test_length = test_length
    );

    bracelet_from_config(
        band    = band_cfg,
        surface = surface_cfg,
        latch   = latch_cfg,
        export  = export_cfg
    );
}

// --- default render --------------------------------------------------------

studded_bracelet(
    circumference = OPEN_STUDS_DEFAULT_CIRCUMFERENCE,
    width         = OPEN_STUDS_DEFAULT_WIDTH,
    thickness     = OPEN_STUDS_DEFAULT_THICKNESS,
    stud_module   = OPEN_STUDS_DEFAULT_STUD,
    stud_pattern  = OPEN_STUDS_DEFAULT_PATTERN,
    stud_rows     = OPEN_STUDS_DEFAULT_ROWS,
    latch         = "buckle",
    mode          = "integral"
);

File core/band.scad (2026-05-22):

// core/band.scad — bracelet substrate geometry.
// MIT licensed. See LICENSE-MIT.

include <config.scad>

// --- flat printable substrate ---------------------------------------------

module band_strip(length, width, thickness, corner = OPEN_STUDS_DEFAULT_CORNER) {
    linear_extrude(height = thickness)
        if (corner > 0)
            offset(r = corner) offset(delta = -corner)
                square([length, width], center = false);
        else
            square([length, width], center = false);
}

function band_relief_enabled(mode, thickness) =
    mode == "inside_slots" || mode == "slots" ||
    (mode == "auto" && thickness >= 3.6);

function band_relief_depth(thickness, relief_depth) =
    max(0, min(
        thickness - 0.6,
        is_undef(relief_depth) ? max(0, thickness - 1.2) : relief_depth
    ));

module band_flex_relief_cuts(
    length,
    width,
    thickness,
    relief_pitch       = 10,
    relief_width       = 1.2,
    relief_depth       = undef,
    relief_edge_margin = 2,
    relief_margin      = OPEN_STUDS_LATCH_MARGIN
) {
    depth = band_relief_depth(thickness, relief_depth);
    slot_y = relief_edge_margin;
    slot_width = max(0, width - 2 * relief_edge_margin);

    if (relief_pitch > 0 && relief_width > 0 && depth > 0 && slot_width > 0)
        for (x = [relief_margin : relief_pitch : length - relief_margin])
            translate([x - relief_width / 2, slot_y, -0.05])
                cube([relief_width, slot_width, depth + 0.1], center = false);
}

module bracelet_band(
    length,
    width,
    thickness,
    corner             = OPEN_STUDS_DEFAULT_CORNER,
    flex_relief        = "none",
    relief_pitch       = 10,
    relief_width       = 1.2,
    relief_depth       = undef,
    relief_edge_margin = 2,
    relief_margin      = OPEN_STUDS_LATCH_MARGIN
) {
    difference() {
        band_strip(length, width, thickness, corner);

        if (band_relief_enabled(flex_relief, thickness))
            band_flex_relief_cuts(
                length,
                width,
                thickness,
                relief_pitch,
                relief_width,
                relief_depth,
                relief_edge_margin,
                relief_margin
            );
    }
}

module bracelet_band_from_config(cfg) {
    bracelet_band(
        length             = band_cfg_length(cfg),
        width              = band_cfg_width(cfg),
        thickness          = band_cfg_thickness(cfg),
        corner             = band_cfg_corner(cfg),
        flex_relief        = band_cfg_flex_relief(cfg),
        relief_pitch       = band_cfg_relief_pitch(cfg),
        relief_width       = band_cfg_relief_width(cfg),
        relief_depth       = band_cfg_relief_depth(cfg),
        relief_edge_margin = band_cfg_relief_edge_margin(cfg),
        relief_margin      = band_cfg_relief_margin(cfg)
    );
}

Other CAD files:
core/latch.scad
core/surface.scad
docs/configurator/bracelet_bundled.scad
latches/buckle.scad
latches/friction_overlap.scad
latches/ladder_strap.scad
latches/loop_post.scad
latches/loop_post_v2.scad
latches/magnetic.scad
latches/mushroom_keyhole.scad
latches/snap.scad
patterns/cluster.scad
patterns/double_row.scad
patterns/gradient_size.scad
patterns/single_row.scad
patterns/staggered.scad
presets/classic_spiked.scad
presets/festival_wide.scad
presets/subtle_daily.scad
sizing_test.scad
studs/cone_spike.scad
studs/diamond.scad
studs/dome.scad
studs/flat_pyramid.scad
studs/heart.scad
studs/hex_bolt.scad
studs/lightning.scad
studs/long_spike.scad
studs/pyramid.scad
studs/rivet.scad
studs/screw_head.scad
studs/star.scad
studs/washer.scad
test_prints/flex_relief_strip.scad
test_prints/latch_lab_ladder_strap.scad
test_prints/latch_lab_loop_post_v2.scad
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

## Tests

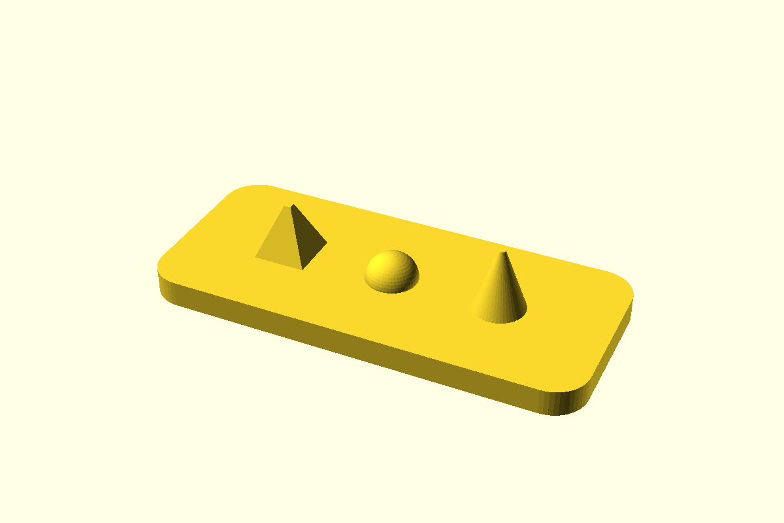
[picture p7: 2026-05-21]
docs/assets/sizing_test.png

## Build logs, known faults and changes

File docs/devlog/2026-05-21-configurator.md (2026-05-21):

# Curved showcase viewer — 2026-05-21

Push 5. The bracelet prints flat but is worn curved; a flat PNG sells nothing. Today shipped the Three.js showcase viewer at [/configurator/](../configurator/) — three presets, real-time bending around a wrist, two-color layer-swap simulator that maps a filament swap at print layer N to a radial color split on the worn bracelet.

## What landed

**Three preset SCAD files** (each a one-`include` + one `studded_bracelet(...)` call):

- **`classic_spiked`** — long-spike staggered double-row + buckle, 180 × 22 × 3 mm. The README's Quick Start example.
- **`festival_wide`** — star studs double-row + loop-post, 200 × 28 × 3 mm. Wider cuff.
- **`subtle_daily`** — flat pyramid single-row + magnetic, 170 × 16 × 3 mm. Work-friendly.

**`docs/configurator/`** — the viewer page:

- `index.html` — vanilla HTML, no Jekyll front matter so Jekyll passes it through unchanged
- `app.js` — Three.js ES module + custom `ShaderMaterial`. Bending math lives in the vertex shader; color split in the fragment shader.
- `style.css` — dark-mode side panel with frosted-glass backdrop blur
- `presets.json` — metadata + suggested colors for each preset
- `stls/` — auto-populated by CI on push

**`build-presets.yml`** — new workflow. Triggers on any change to `presets/*.scad`, `bracelet.scad`, `studs/**`, `latches/**`, `patterns/**`. Renders each preset to STL via the headless `openscad` CLI (no xvfb needed for STL export, unlike PNG renders). Auto-commits with the same `git add` → `git diff --cached --quiet` pattern that build-scad uses, plus `[skip ci]` to keep pages.yml from re-firing on the bot's STL commit.

**Pages URL cleanup** — `pages.yml`'s staging step now flattens `docs/` into the site root via `cp -r docs/. _src/` instead of nesting under `_src/docs/`. Result: `/configurator/`, `/devlog/`, `/explainers/`, `/assets/` are all clean root-level URLs.

## The bending math

The vertex shader takes the flat OpenSCAD coordinates and wraps them around the world Y axis:

```glsl
float angle = (position.x - circumference * 0.5) / circumference * 2π;
float r = wristRadius + position.z;       // z becomes radial
vec3 bent = vec3(r * sin(angle), position.y - bandWidth/2, r * cos(angle));
```

The non-obvious thing — and the reason this view is interesting for filament planning, not just decorative — is that **in the flat geometry, z is the print-layer axis** (layer N at z = N × 0.2 mm). After bending, z becomes the *radial direction*. So a color swap "at layer N" appears as a swap between the inner-wrist and outer-visible surface of the bracelet, with the boundary at radial distance `wristRadius + N × 0.2 mm`.

Practical consequence: if you set the swap at layer 7 on a 15-layer (3 mm) band, you get a thin black inner sleeve and a thick red outer layer — what you'd actually see on the worn print. Slide the swap toward the top and the visible red shrinks to a thin top band, what people call a "color flash" in TPU filament-swap prints.

The fragment shader uses `smoothstep(uSwapZ - 0.1, uSwapZ + 0.1, vFlatZ)` for the transition so it reads like a real print's layer-to-layer color transition, not a sharp cliff.

## Lighting note

Lighting in the shader is a basic Lambert-plus-ambient term (`0.35 + 0.65 * max(dot(normal, lightDir), 0)`). For correct shading the original mesh normals are rotated by the same bend matrix as the positions — without this step, the bent geometry would be lit as if it were still flat, which produces visible artifacts especially on the studs.

## Open questions to revisit

- **Three.js from CDN.** `unpkg.com/three@0.160.0` is convenient but adds a runtime dependency on a third-party CDN. If reliability matters, vendor the modules into `docs/configurator/vendor/` and reference relatively. Not a Push 5 blocker.
- **Wrist size selector deferred.** Showing the same STL bent at different radii distorts geometry (parts overlap at small radii). Better long-term: bake separate STLs per size, or accept the distortion and warn.
- **No camera controls.** The bracelet auto-rotates; users can't tumble or zoom. Adding `OrbitControls` is a five-line drop-in but I want to see the auto-rotate land first.
- **STL git bloat.** Three STLs at maybe 500 KB each is fine; if the preset catalog grows large, Git LFS or a CI-uploads-to-bucket pattern is the next step. See `SHAREABLE-CAD.md` for the storefront pattern.

## Verification

- `openscad -o /tmp/test.stl presets/classic_spiked.scad` produces a manifold mesh
- After push, `build-presets.yml` runs green and a bot commit lands with STLs under `docs/configurator/stls/`
- After pages.yml redeploys, https://jmcpheron.github.io/open-studs/configurator/ returns HTTP 200, the bracelet renders, controls work

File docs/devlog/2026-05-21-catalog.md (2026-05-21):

# Catalog expansion — 2026-05-21

Push 4. Now that the Shareable CAD pipeline is alive, the catalog has been thin (mostly geometric primitives). Adding subculture-specific designs and making the latch stubs real.

## What landed

**Six new studs** (filed under the existing contract — `module stud_<name>(size, tip_radius, height)`, origin at base center, +Z axis):

- **Industrial set** — `rivet` (mushroom-cap button), `hex_bolt` (cylinder with `$fn=6`, optional chamfer), `washer` (flat ring, negative-space)
- **Festival / symbolic set** — `star` (5-point polygon, `tip_radius` rounds the tips), `heart` (two circles + a triangle, kawaii option), `lightning` (zigzag polygon, cyberpunk)

Each file has a development render at the bottom (`stud_<name>(size = 8);`) so you can open it standalone in OpenSCAD with F5.

**Three latches converted from stubs to working geometry**:

- **`snap`** — peg-and-socket: both ends carry a flat tab that extends past the band edge; left tab has a flared peg pointing up, right tab has a matching socket on its underside. No added hardware.
- **`loop_post`** — left end has a T-headed post rising from the band's top surface; right end has a loop-frame extending past the band. Slip loop over post; T-head captures.
- **`magnetic`** — small puck on each band end with a pocket for a 6 mm × 2 mm neodymium disc magnet. Print, drop magnets in, cyanoacrylate. Polarity is the user's responsibility.

**Dispatch fix**: the previous `place_latch()` in `bracelet.scad` mirrored the right-end invocation, which placed the buckle tongue INSIDE the band rather than extending past it (visible in Push 3's first auto-render — the right end looked truncated). Replaced with a clean translate-only convention: each latch defines its left half extending -X and right half extending +X, the dispatch translates the right call to `band_length` without mirroring. The new latches were written to this convention from the start.

**`params.py`**: extended `STUD_HEIGHT_MULTIPLIERS` with the 6 new entries; added `MAGNET_DIAMETER`, `MAGNET_THICKNESS`, `MAGNET_TOLERANCE`, `MAGNET_PUCK_HEIGHT`. The drift test will catch any divergence between these and what the latch SCAD files use.

## What got free

- `tests/test_signatures.py` is parametrized over `_scad_files()` — the 6 new studs and 3 converted latches automatically gain signature tests. Test count went from 24 to 30 with no test edits.
- `docs/explainers/studs.md` automatically picks up the new entries on the next `uv run explainers build`. CI will regenerate it on push.
- `bracelet.scad`'s dispatch-completeness tests would have caught it if I'd added a new stud file under `studs/` and forgotten the `place_stud()` branch. (Didn't trigger because I remembered the branches, but the safety net is there.)

## What's next

Push 5 — the curved showcase viewer at `jmcpheron.github.io/open-studs/configurator/`. Three.js + vertex-shader bending + two-color layer-swap simulator. The catalog work in this push is what gives that viewer something to show off.

## Notes

- Magnetic latch's `band_thickness` guard emits an OpenSCAD `echo` warning if the band is too thin for the puck-pocket geometry (default 3 mm is fine; 2 mm would fail). Worth catching at compile time before someone wastes filament.
- `friction_overlap` was not in this push's scope (it's "working enough" — adds no hardware). Its taper geometry is still a stub; that's a separate iteration.
- Buckle's adjustment-hole spacing and pyramid construction approach are still at the defaults flagged in `docs/devlog/2026-05-20-day-one.md`. Open for design iteration.

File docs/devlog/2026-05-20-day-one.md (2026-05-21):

# Day one — 2026-05-20

First push to `main`. Setting the project up as the fourth instance of the **Shareable CAD** pattern (see [`SHAREABLE-CAD.md`](../../SHAREABLE-CAD.md)), with OpenSCAD as source-of-truth instead of Onshape. The earlier three projects (gear card, Pounce-a-Pult, vault) all use Onshape; `open-studs` is the first time the pattern gets tested with a code-first parametric tool.

## What landed

- **Vertical-slice geometry.** `bracelet.scad` + `sizing_test.scad`, every stud working (7 designs), every pattern working except `cluster` and `gradient_size` (signatures locked, bodies stubbed), 2 of 5 latches working (`buckle`, `friction_overlap`), the other 3 stubbed. The README's exact Quick Start example (`long_spike` + `staggered` + `buckle` + `integral`) renders end-to-end.
- **Python kernel skeleton.** `src/open_studs/params.py` mirrors every default. `studslab inspect` works against any `.scad` file (regex-based, no OpenSCAD dependency). `explainers build` generates four markdown pages under `docs/explainers/` from the parameter mirror.
- **Pattern docs.** `SHAREABLE-CAD.md` adapted from the pycon2026 version with an "OpenSCAD vs Onshape variant" comparison table. `CONTRIBUTING.md` carries the module-signature contract.
- **Dual licensing** (MIT for code, CC BY 4.0 for designs) in place.

## What's deferred

- **Tests** (Push 2). Drift test between `params.py` and the auto-generated explainer pages; signature test for every `.scad` file in `studs/`, `latches/`, `patterns/`.
- **CI workflows** (Push 3). Auto-commit `build-scad.yml`, `build-explainers.yml`, `pages.yml`.
- **MakerWorld + Printables** — once the first preset is print-tested and bundled.
- **`openscad-wasm` configurator** at `jmcpheron.github.io/open-studs` — additive to the storefronts, for live customization before download.

## Open design questions to revisit

These were left at reasonable defaults in Push 1 but are worth iterating on:

1. **Pyramid construction approach.** Currently `cylinder($fn=4)` because `tip_radius` drops in cleanly as the top radius. Alternatives: explicit `polyhedron` (more control, no fillet); `hull()` over a square base and a point (clean, harder to flatten); `minkowski` for true fillets (slow). See the LEARNING-MODE comment in `studs/pyramid.scad`.
2. **Buckle adjustability granularity.** Currently 5 holes at 5 mm = 20 mm of adjustability. Goth wants fewer/wider; festival wants more/tighter. See `latches/buckle.scad`.
3. **Single-row spacing strategy.** Currently auto-fits to the band length so studs sit evenly with the latch margin respected. Alternative: fixed mm spacing, accept the leftover gap. See `patterns/single_row.scad`.

## Notes

- OpenSCAD was not installed in the dev environment that wrote this commit. The user is the one running F6 / CLI renders locally. The Python kernel `studslab inspect` and `explainers build` were both smoke-tested against the committed files; both work.
- `studslab render` / `build` / `explode` / `spin` are advertised in the CLI's `--help` but raise `not yet implemented`. They land alongside the CI workflows in Push 3 (when OpenSCAD CLI is wired into the toolchain).

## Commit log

2026-05-21 Push 1: scaffold + vertical-slice geometry + Python kernel skeleton
    Stand up open-studs as the fourth instance of the Shareable CAD pattern
    (see SHAREABLE-CAD.md), with OpenSCAD as source-of-truth in place of
    Onshape.
    Vertical slice:
    - bracelet.scad with the README's exact Quick Start signature, dispatching
    on stud_module / stud_pattern / latch / mode strings
    - sizing_test.scad with three reference studs
    - 7 working stud designs (pyramid, dome, cone_spike, long_spike, diamond,
    flat_pyramid, screw_head)
    - 3 working patterns (single_row, double_row, staggered); cluster and
    gradient_size stubbed with signature locked
    - 2 working latches (buckle, friction_overlap); snap, loop_post, magnet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
    [bracelet.scad, buckle.scad, cluster.scad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]
2026-05-21 Push 2: tests — signature contract + drift enforcement
    tests/test_signatures.py — every .scad under studs/, latches/, patterns/
    must implement the module/function signature contract from CONTRIBUTING.md:
    - studs/<name>.scad → module stud_<name>(...)
    - latches/<name>.scad → module latch_<name>(...)
    - patterns/<name>.scad → function pattern_<name>(...)
    Plus three dispatch-completeness tests asserting bracelet.scad has a
    branch for every file in those directories — so adding a new stud
    without wiring it into place_stud() fails CI.
    tests/test_no_drift.py — re-runs explainers build into memory and asserts
    the committed pages under docs/explainers/*.md match byte-for-by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
2026-05-21 Push 3: CI workflows — test, build-explainers, build-scad, pages
    Four GitHub Actions workflows, each watching its own input paths and (for
    the auto-commit ones) writing to disjoint output paths so they can race
    without conflict.
    test.yml — runs uv run pytest on every PR and push to main. Caches the
    uv environment between runs.
    build-explainers.yml — on changes to src/explainers/ or
    src/open_studs/params.py, regenerate docs/explainers/*.md and auto-commit
    with a 5-attempt rebase-and-retry loop. Bot commits use [skip ci] so they
    don't trigger downstream workflows.
    build-scad.yml — on .scad changes, apt-install openscad + xvfb, render
    bracelet.scad and sizing_test.scad to docs/assets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
2026-05-21 Add CI badges and SHAREABLE-CAD pattern reference to README
2026-05-21 Switch pages workflow to Jekyll; tickle build-{explainers,scad}
    Pages workflow was serving raw .md as static files, so requests to /
    returned 404 with no index.html. Switch to actions/jekyll-build-pages so
    markdown is rendered to HTML with the minima theme. README.md becomes
    index.md; SHAREABLE-CAD.md, CONTRIBUTING.md, etc. ship at the site root.
    Also tickling src/open_studs/params.py and bracelet.scad with comment-only
    edits so the build-explainers and build-scad workflows trigger for the
    first time — they were registered on the previous push but didn't fire
    (GitHub doesn't trigger workflows on the same push that introduces them).
    The auto-commit loops should now run end-to-end.
    [bracelet.scad]
2026-05-21 Fix auto-commit workflows: git diff misses untracked files
    The first run of build-scad created docs/assets/*.png from scratch.
    Because the files were untracked, `git diff --quiet docs/assets/`
    returned clean and the commit step was skipped — the renders existed
    on the runner's disk but never reached main.
    Fix is to `git add` first, then check `git diff --cached --quiet`.
    The staged-diff check sees both modifications AND new files.
    Same bug existed in build-explainers.yml; fixed identically.
2026-05-21 Push 4: catalog expansion — 6 new studs + 3 working latches
    Studs added (each follows the contract in CONTRIBUTING.md):
    - Industrial set: rivet (mushroom-cap), hex_bolt (hex head, optional chamfer),
    washer (flat ring with through-hole)
    - Festival/symbolic set: star (5-point), heart (two circles + triangle),
    lightning (zigzag bolt)
    Latches converted from stub to working geometry:
    - snap — peg-and-socket on extending tabs (no hardware)
    - loop_post — T-post + loop-frame
    - magnetic — pucks at each end with pockets for 6mm × 2mm neodymium discs
    Also fixed place_latch()'s right-end convention in bracelet.scad: it used
    to translate-and-mirror, which placed the buckle tongue INSIDE th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
    [bracelet.scad, heart.scad, hex_bolt.scad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]
2026-05-21 Push 5: curved showcase viewer + presets + flatten pages URLs
    A Three.js viewer at /configurator/ shows the bracelet bent around a wrist
    with a two-color layer-swap simulator. The viewer is a showcase, not a CAD
    tool — pre-baked STLs cover the catalog; no parametric SCAD compilation in
    the browser.
    Bending math: the flat OpenSCAD coordinates wrap around the world Y axis.
    In flat geometry, z is the print-layer axis; after bending, z becomes the
    radial direction. So a color swap "at layer N" appears as a swap between
    the inner-wrist surface and the outer visible surface — what you'd
    actually see on a real filament-swap print. This is the conceptual
    payload of the viewer, not just decorati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
    [classic_spiked.scad, festival_wide.scad, subtle_daily.scad]
2026-05-21 Tickle build-presets and pages workflows after Push 5 introduction
    [classic_spiked.scad]
2026-05-21 Fix .gitignore: allow docs/configurator/stls/*.stl to be committed
    build-presets.yml was rendering STLs successfully but the auto-commit's
    `git add docs/configurator/stls/` saw them as ignored and added nothing.
    The "No changes to preset STLs" message in the log was technically true
    once git applied .gitignore — but masked the real problem.
    Adding `!docs/configurator/stls/*.stl` exempts the tracked-artifact path
    the same way `!presets/*.stl` already did. Re-pushing triggers another
    build-presets run; this time the STLs should land on main.
2026-05-21 Re-tickle: trigger build-presets and pages after gitignore fix
    [classic_spiked.scad]
2026-05-21 ci: regenerate preset STLs [skip ci]
    [classic_spiked.stl, festival_wide.stl, subtle_daily.stl]
2026-05-22 Update bracelet.scad and configurator files for improved modularity and usability
    - Refactored bracelet.scad to enhance the API with new entry points for better compatibility and usability.
    - Updated the configurator to support a more structured data model for band, surface, latch, and export configurations.
    - Adjusted the README and CONTRIBUTING.md to reflect changes in the module structure and contribution guidelines.
    - Enhanced the .gitignore to include additional directories for better management of build outputs.
    - Regenerated STL files for presets to ensure they align with the latest changes.
    [band.scad, bracelet.scad, classic_spiked.scad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]
2026-05-22 Add experimental latch designs and update README
    - Introduced new latch designs: mushroom_keyhole, ladder_strap, and loop_post_v2 in latch.scad.
    - Updated README to include links to experimental latch coupons and their descriptions.
    - Enhanced the place_latch function to support the new latch types.
    [ladder_strap.scad, latch.scad, latch_lab_ladder_strap.scad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]
2026-05-22 docs: improve pages landing page
2026-05-22 fix: flip mushroom_keyhole orientation so insertion shortens the band
    Swap the wide entry hole and narrow capture hole positions along the tab
    so fastening matches intuition: squeeze the band shorter to push the head
    through the wide hole, then release and the band relaxes into the narrow
    capture slot. The previous arrangement required lengthening the band to
    insert, then tightening to lock.
    Also make the throat cube construction direction-agnostic (min/abs) so
    swapping the two X constants doesn't produce a negative-width cube.
    https://claude.ai/code/session_01HsJoWpEsDHNAiFBSHwXCA7
    [mushroom_keyhole.scad]
2026-05-22 feat(configurator): drive 3D preview from controls; per-type stud and latch geometry
    The deployed configurator was a demo: it loaded one of three pre-baked STLs
    and the controls only nudged shader uniforms. Changing stud type, width,
    thickness, latch, or surface mode had no visible effect on the mesh.
    Now the preview is parametric — every control rebuilds geometry to match the
    OpenSCAD source:
    - All 13 stud types render with correct dimensions (pyramid corners at
    ±size/2, hex flat-to-flat = size, diamond as bipyramid via LatheGeometry,
    washer as flat annulus, etc.)
    - All 9 latches dispatch to dedicated builders with real through-holes via
    THREE.Shape + THREE.Path holes (buckle ton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
2026-05-22 feat(configurator): bundle the SCAD library into the .scad download
    Downloads previously emitted `use <bracelet.scad>`, which only worked if the
    user had the whole repo (1473 lines across 30 files) co-located with the
    download. Now the download is self-contained: the configurator fetches a
    pre-bundled bracelet_bundled.scad and prepends it to the user's config so the
    downloaded .scad renders in OpenSCAD without any setup.
    - scripts/bundle_scad.py concatenates the SCAD source in dependency order,
    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
    [bracelet_bundled.scad]
